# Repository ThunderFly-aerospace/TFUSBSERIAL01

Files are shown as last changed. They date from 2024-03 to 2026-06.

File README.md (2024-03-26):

# TFUSBSERIAL01 - USB-C to serial converter with Pixhawk telemetry JST-GH connector

The converter is designed to service operations on UAVs. It respects the [Pixhawk DS-009](https://github.com/pixhawk/Pixhawk-Standards/blob/master/DS-009%20Pixhawk%20Connector%20Standard.pdf) connector standard.

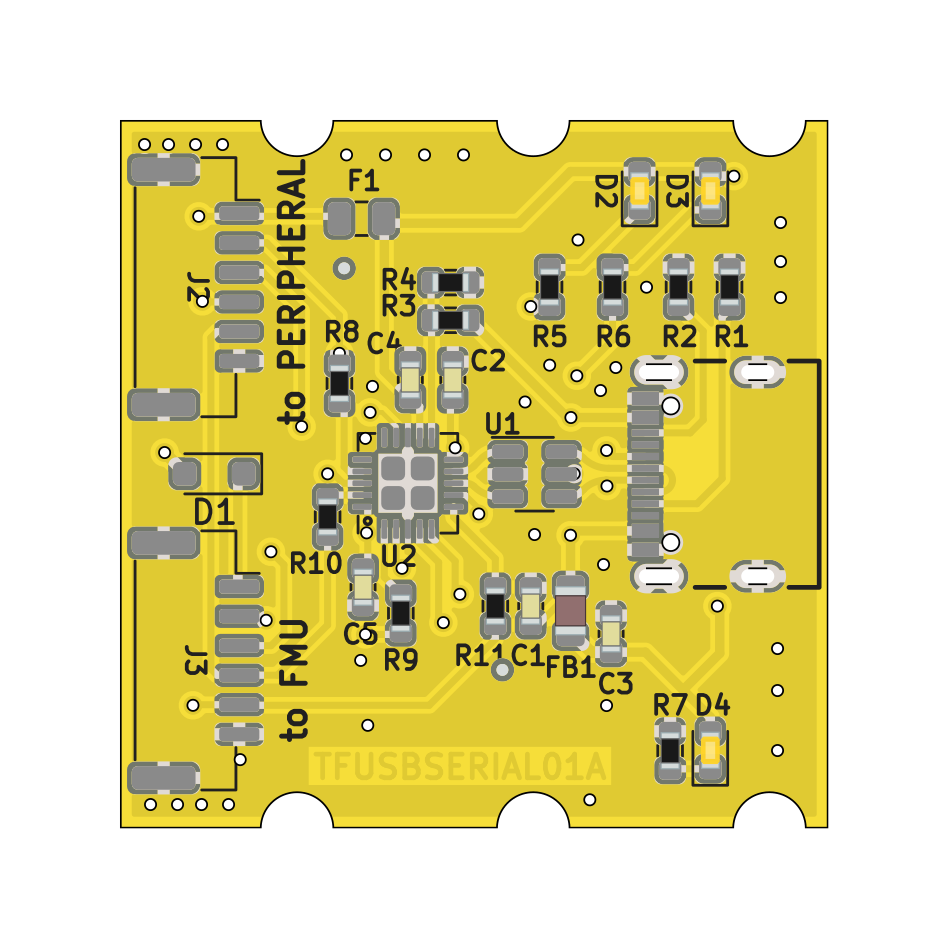
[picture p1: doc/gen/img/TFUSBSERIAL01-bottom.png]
TFUSBSERIAL01 Bottom


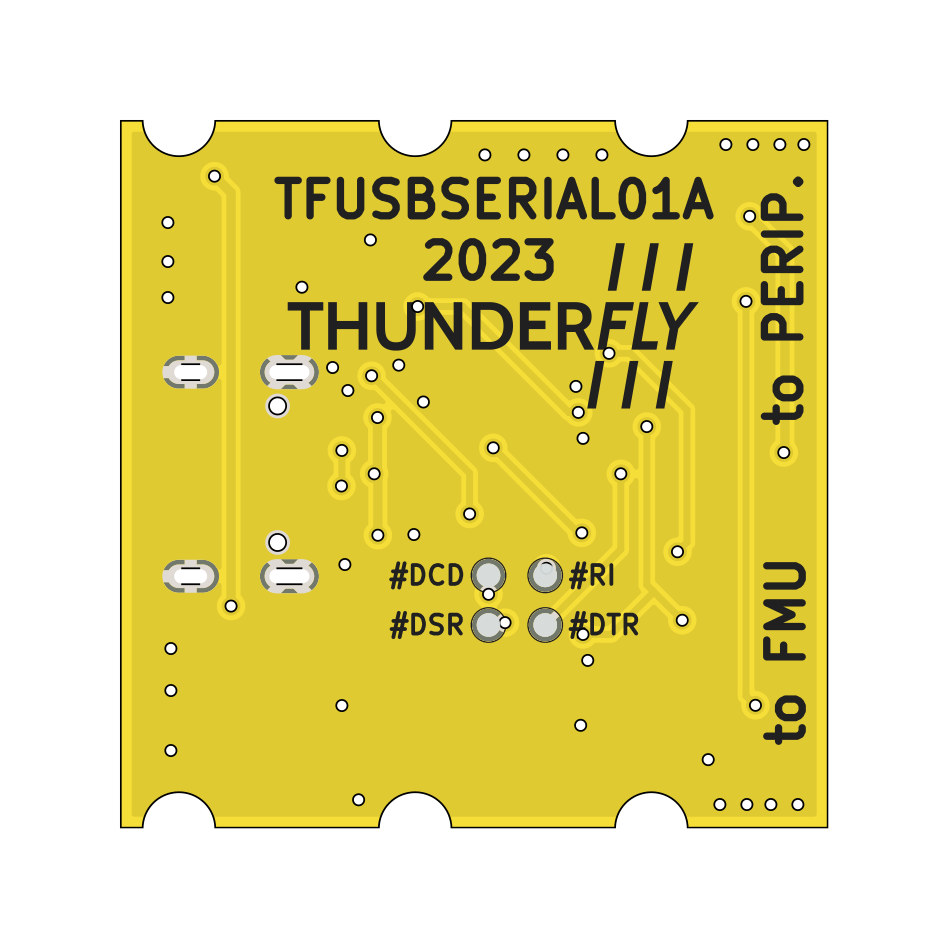
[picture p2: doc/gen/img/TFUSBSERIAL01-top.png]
TFUSBSERIAL01 Top


## Key features
 
  * Could be connected to both peripheral or FMUs
  * The FMU and peripheral connectors are separated, therefore there is no need for a special RX/TX cross-cable
  * Could be used for sniffing serial communication on telemetry links between autopilot and its peripheral (Both connectors could be used at once)
  * Supports hardware flow control
  * The power delivered from USB is protected from excess current possibly drawn by peripheral or FMU
  * The accidental power from FMU to USB is protected by reverse diode

### Where to Get It?
TFUSBSERIAL can be bought directly from ThunderFly via [email contact](https://www.thunderfly.cz/contact-us.html). The email can also be used if there are specific requirements for custom modifications and accessories (cables for example) or if the product will be inquired in significant quantities.

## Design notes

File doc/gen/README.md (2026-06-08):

# PCB

Board size: 30.0x30.0 mm (1.18x1.18 inches)

- This is the size of the rectangle that contains the board
- Thickness: 1.6 mm (63 mils)
- Material: FR4
- Finish: None
- Layers: 2
- Copper thickness: 35 µm

Solder mask: TOP / BOTTOM

- Color: Yellow

Silk screen: TOP / BOTTOM

- Color: Black

Stackup:

| Name | Type | Color | Thickness [µm]| Material | Er | Loss tan |
|---|---|---|---|---|---|---|
| F.SilkS | Top Silk Screen | Black | | | | |
| F.Mask | Top Solder Mask | Yellow | 10 | | | |
| F.Cu | copper | | 35 | | | |
| dielectric 1 | core | | 1510 | FR4 | 4.5 | 0.020 |
| B.Cu | copper | | 35 | | | |
| B.Mask | Bottom Solder Mask | Yellow | 10 | | | |
| B.Paste | Bottom Solder Paste  | | | | | |
| B.SilkS | Bottom Silk Screen | Black | | | | |

# Important sizes

Clearance: 0.2 mm (8 mils)

Track width: 0.2 mm (8 mils)

- By design rules: 0.2 mm (8 mils)

Drill: 0.5 mm (20 mils)

- Vias: 0.5 mm (20 mils) [Design: 0.4 mm (16 mils)]
- Pads: 0.65 mm (26 mils)
- The above values are real drill sizes, they add 0.1 mm (4 mils) to plated holes (PTH)

Via: 0.8/0.4 mm (31/16 mils)

- By design rules: 0.4/0.3 mm (16/12 mils)
- Micro via: yes [0.2/0.1 mm (8/4 mils)]
- Buried/blind via: yes
- Total: 59 (thru: 59 buried/blind: 0 micro: 0)

Outer Annular Ring: 0.15 mm (6 mils)

- By design rules: 0.05 mm (2 mils)

Eurocircuits class: 4B
- Using min drill 0.5 mm for an OAR of 0.15 mm

# General stats

Components count: (SMD/THT)

- Top: 0/6 (THT)
- Bottom: 29/0 (SMD)

Defined tracks:

- 0.2 mm (8 mils)
- 0.3 mm (12 mils)
- 0.4 mm (16 mils)
- 0.5 mm (20 mils)
- 0.6 mm (24 mils)
- 0.8 mm (31 mils)
- 0.86 mm (34 mils)

Used tracks:

- 0.2 mm (8 mils) (4) defined: yes
- 0.25 mm (10 mils) (3) defined: no
- 0.3 mm (12 mils) (128) defined: yes
- 0.4 mm (16 mils) (32) defined: yes
- 0.5 mm (20 mils) (6) defined: yes

Defined vias:

- 0.5/0.3 mm (20/12 mils)
- 0.8/0.4 mm (31/16 mils)

Used vias:

- 0.8/0.4 mm (31/16 mils) (Count: 59, Aspect: 2.0 A) defined: yes

Holes (excluding vias):

- 0.65 mm (26 mils) (2)
- 3.0 mm (118 mils) (6)

Oval holes:

- 0.6x1.4 mm (24x55 mils) (2)
- 0.6x1.7 mm (24x67 mils) (2)

Drill tools (including vias and computing adjusts and rounding):

- 0.5 mm (20 mils) (59)
- 0.65 mm (26 mils) (2)
- 0.7 mm (28 mils) (4)
- 3.0 mm (118 mils) (6)

Solder paste stats:

Using a paste with 87.75 % alloy, that has an specific gravity for the alloy of 7.4 g/cm³
and 1.0 g/cm³ for the flux. This paste has an specific gravity of  4.15 g/cm³.

The stencil thickness is  0.12 mm.

| Side | Pads with paste | Area [mm²] | Paste [g] |
|---|---|---|---|
| Total  | 102 | 75.81 | 0.38 |

Note: this is just an approximation to the theoretical value. Margins of the solder mask and waste aren't computed.

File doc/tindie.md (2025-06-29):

Simplify your UAV maintenance with the **TFUSBSERIAL01**, the essential tool for debugging and servicing UAV systems. This USB-C to serial converter is fully compliant with the [Pixhawk DS-009 connector standard](https://github.com/pixhawk/Pixhawk-Standards/blob/master/DS-009%20Pixhawk%20Connector%20Standard.pdf), ensuring seamless integration with your avionics equipment.

#### **Key Features:**
- **Dual Connection Flexibility:** Easily connect to both peripheral or FMUs without the need for special RX/TX crossover cables.
- **Simultaneous Communication:** Capable of sniffing serial communication on telemetry links, utilizing both connectors at once.
- **Advanced Safety Features:** Includes excess current protection for USB power and a reverse diode to prevent accidental power flow from FMU to USB.
- **Hardware Flow Control Support:** Ensures reliable data transfer, crucial for critical debugging tasks.

#### Easy Usage
Connect the FMU or peripheral device to the corresponding Pixhawk connector and utilize standard serial terminal tools for effective communication.

#### Effortless Self-Testing
Test cable functionality by connecting the "to FMU" and "to Peripheral" connectors, simulating a local echo for straightforward self-diagnostics.

# The package includes
- TFUSBSERIAL01A protected by the heat-shrinking tube
- 15cm UART/TELEM/SERIAL cable with JST-GH connectors. Color-coded by [ThunderFly color scheme](https://docs.thunderfly.cz/avionics/TFCAB01/).

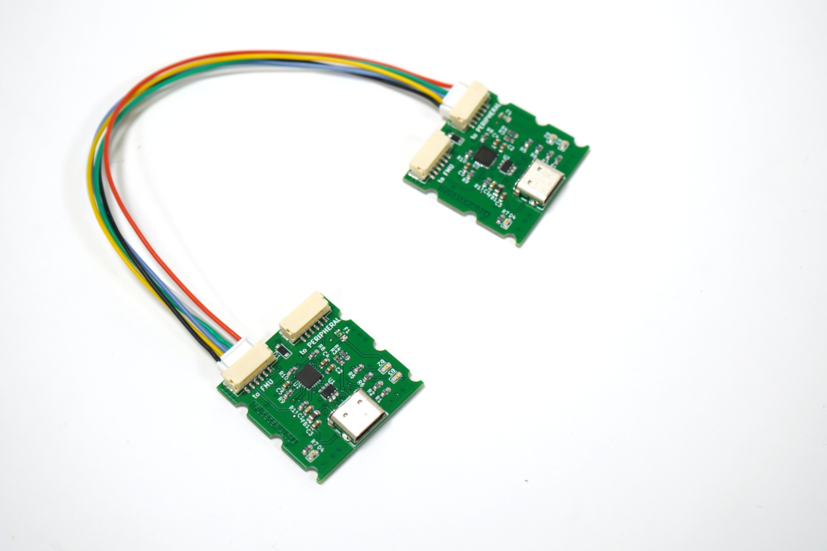
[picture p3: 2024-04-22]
doc/img/TFUSBSERIAL_MCU_PERIPHERAL.JPG

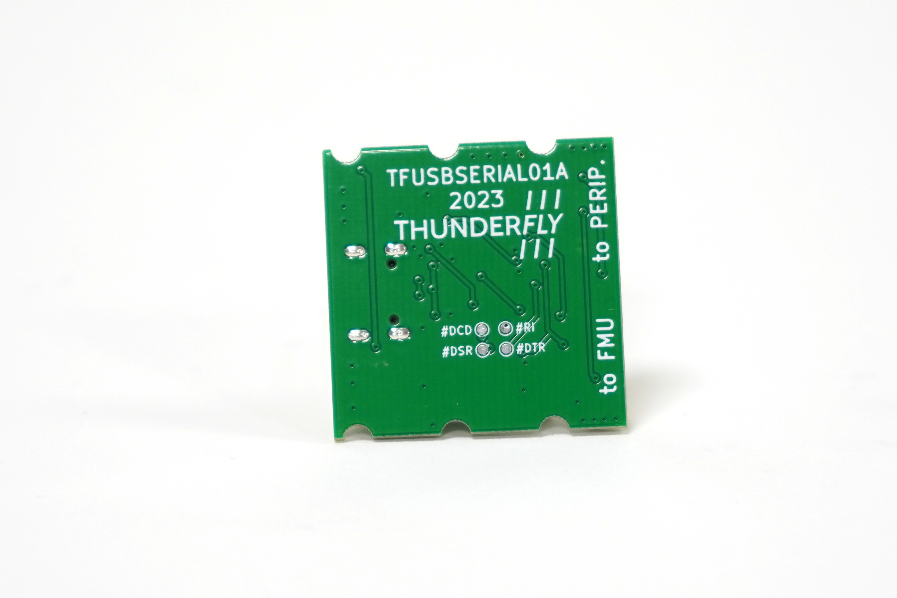
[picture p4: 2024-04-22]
doc/img/TFUSBSERIAL01_PCB.jpg

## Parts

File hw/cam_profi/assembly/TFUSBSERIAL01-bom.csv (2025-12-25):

Component | Description | Part | References | Value | Footprint | Quantity Per PCB | Datasheet | ust_id
1 | Unpolarized capacitor | C | C1 | 10nF | C_0603_1608Metric | 1 | ~ | 5c70984812875079b91f8bef
2 | Unpolarized capacitor | C | C2C4C5 | 100nF | C_0603_1608Metric | 3 | ~ | 5c70984812875079b91f8bf2
3 | Unpolarized capacitor | C | C3 | 10uF | C_0603_1608Metric | 1 | ~ | 5c70984812875079b91f8bf5
4 | Light emitting diode | LED | D3D4 | GREEN | LED_0603_1608Metric | 2 | ~ | 60d582331287500165f859d0
5 | Light emitting diode | LED | D2 | RED | LED_0603_1608Metric | 1 | ~ | 60d581db1287500165f859a2
6 | Diode | D | D1 | SRL23 | D_SOD-323_HandSoldering | 1 | https://www.tme.eu/Document/039d7772a3e1de850ecf12d397e62c7b/srl23.pdf | 651003fd462c6d9e72054b2f
7 | Resettable fuse, polymeric positive temperature coefficient | Polyfuse | F1 | 350mA | Fuse_0805_2012Metric | 1 | ~ | 650b8191462c6d9e7205477b
8 | Ferrite bead, small symbol | FerriteBead_Small | FB1 | BLM21PG300SN1D | L_0805_2012Metric | 1 | ~ | 5c70984412875079b91f87fd
9 | 1x07 2.54 mm pitch header | SM06B-GHS-TB | J2J3 | SM06B-GHS-TB | JST_GH_SM06B-GHS-TB_1x06-1MP_P1.25mm_Horizontal | 2 |  | 5fa0f70212875025b3977932
10 | USB 2.0-only Type-C Receptacle connector | USBC_USB4105-GF-A | J1 | USBC_USB4105-GF-A | USBC GCT_USB4105-GF-A | 1 |  | 5fa0f94612875025b397795e
11 | Resistor | R | R8R9R10R11 | 100R | R_0603_1608Metric | 4 | ~ | 5c70984512875079b91f8956
12 | Resistor | R | R6R7 | 130R | R_0603_1608Metric | 2 | ~ | 5cd08b17128750448e4542b1
13 | Resistor | R | R5 | 287R | R_0603_1608Metric | 1 | ~ | 651a975c462c6d9e7205504d
14 | Resistor | R | R3 | 4k7 | R_0603_1608Metric | 1 | ~ | 5c70984512875079b91f8960
15 | Resistor | R | R1R2 | 5k1 | R_0603_1608Metric | 2 | ~ | 628d1404dc56076e9a223650
16 | Resistor | R | R4 | 10k | R_0603_1608Metric | 1 | ~ | 5c70984512875079b91f8962
17 | Full Speed USB to Full Handshake UART, QFN-20 | FT231XQ | U2 | FT231XQ | QFN-20-1EP_4x4mm_P0.5mm_EP2.5x2.5mm | 1 | https://www.ftdichip.com/Support/Documents/DataSheets/ICs/DS_FT231X.pdf | 605d7fe0128750769e769adb
18 | Very low capacitance ESD protection diode, 2 data-line, SOT-23-6 | USBLC6-2SC6 | U1 | USBLC6-2SC6 | SOT-23-6 | 1 | https://www.st.com/resource/en/datasheet/usblc6-2.pdf | 5e82e0691287502a334a778c

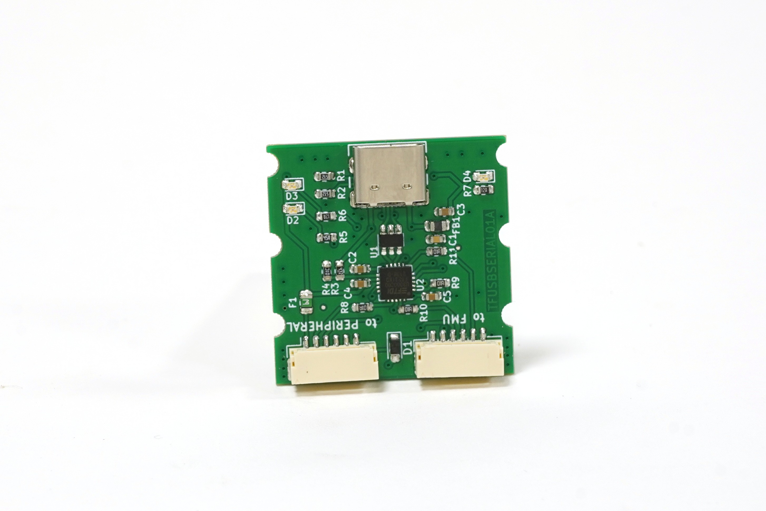
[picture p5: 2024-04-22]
doc/img/TFUSBSERIAL01_components.jpg

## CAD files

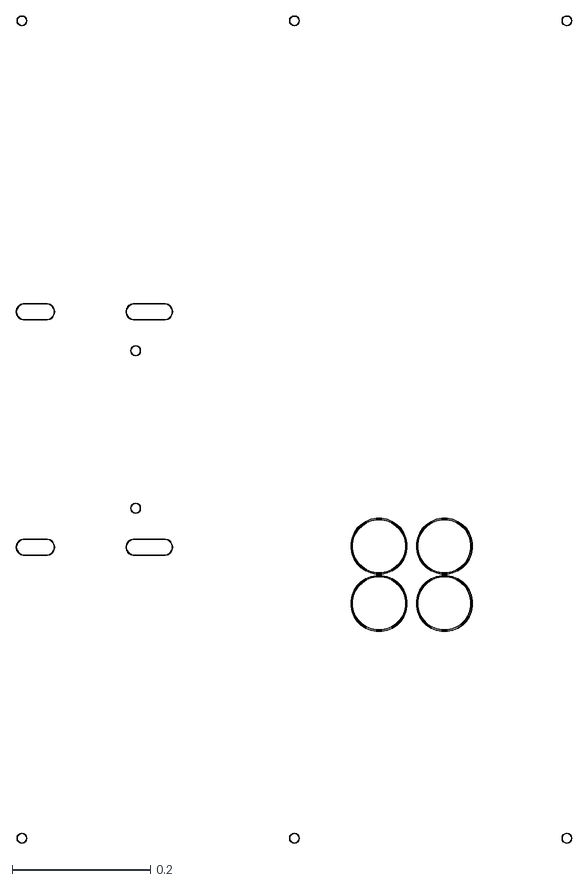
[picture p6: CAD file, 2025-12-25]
doc/gen/dxf/TFUSBSERIAL01-F_Courtyard.dxf
0.802 x 1.19

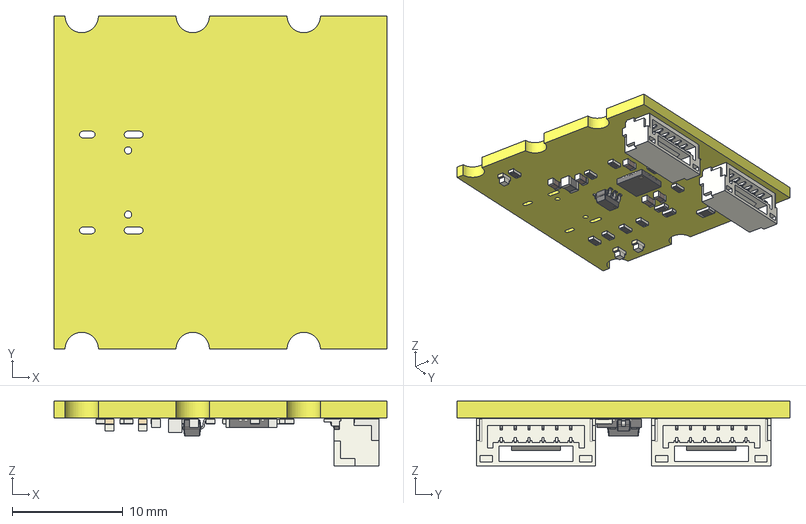
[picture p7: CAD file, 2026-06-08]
doc/gen/TFUSBSERIAL01.step
30.0 x 30.0 x 5.84 mm
D_SOD-323
LED_0603_1608Metric x 3
C_0603_1608Metric x 5
R_0603_1608Metric x 11
L_0805_2012Metric
JST_GH_SM06B-GHS-TB_1x06-1MP_P1.25mm_Horizontal x 2
QFN-20-1EP_4x4mm_P0.5mm_EP2.5x2.5mm
SOT-23-6
Fuse_0805_2012Metric
kibot_sx842oss_PCB

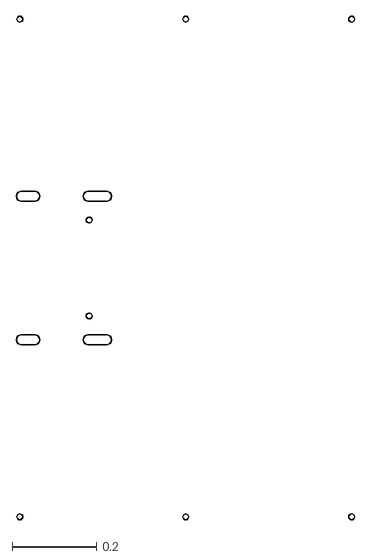
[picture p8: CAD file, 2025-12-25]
doc/gen/dxf/TFUSBSERIAL01-User_Drawings.dxf
0.802 x 1.19

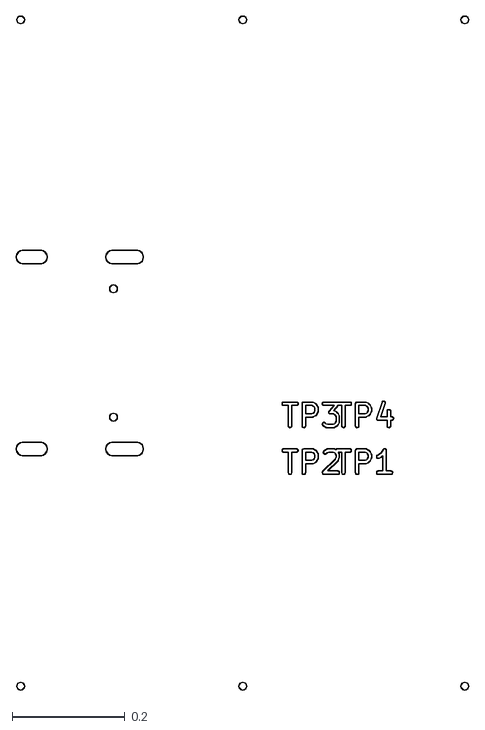
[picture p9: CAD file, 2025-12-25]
doc/gen/dxf/TFUSBSERIAL01-F_Fab.dxf
0.802 x 1.19

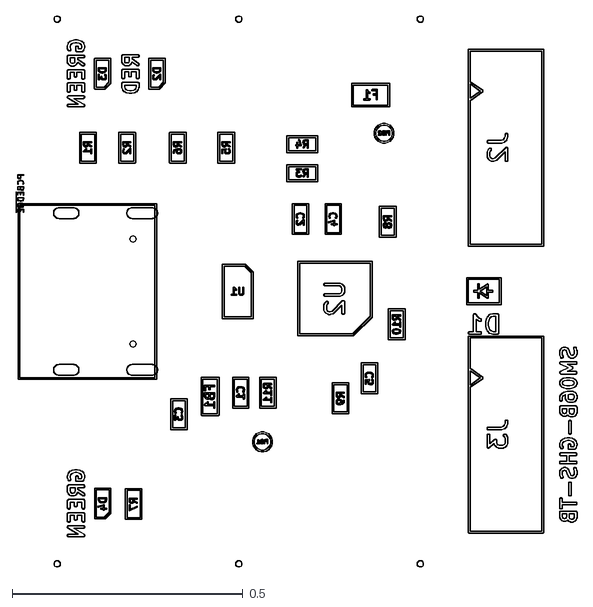
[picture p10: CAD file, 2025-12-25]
doc/gen/dxf/TFUSBSERIAL01-B_Fab.dxf
1.22 x 1.19

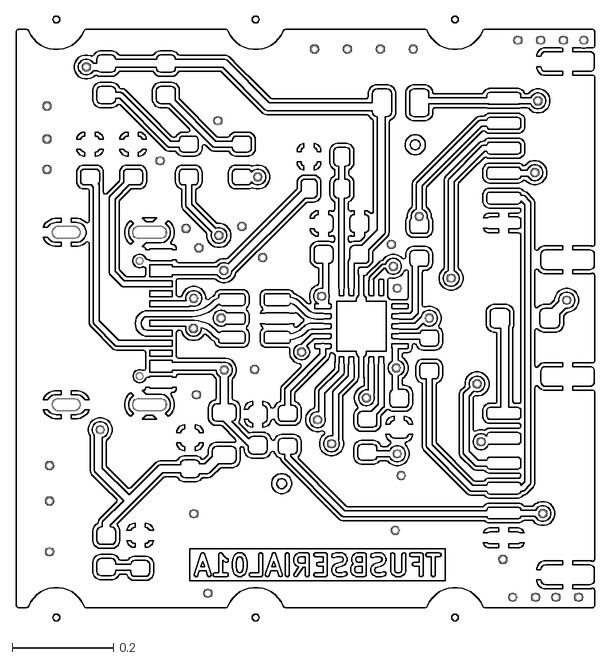
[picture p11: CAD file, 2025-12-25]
doc/gen/dxf/TFUSBSERIAL01-B_Cu.dxf
1.14 x 1.19

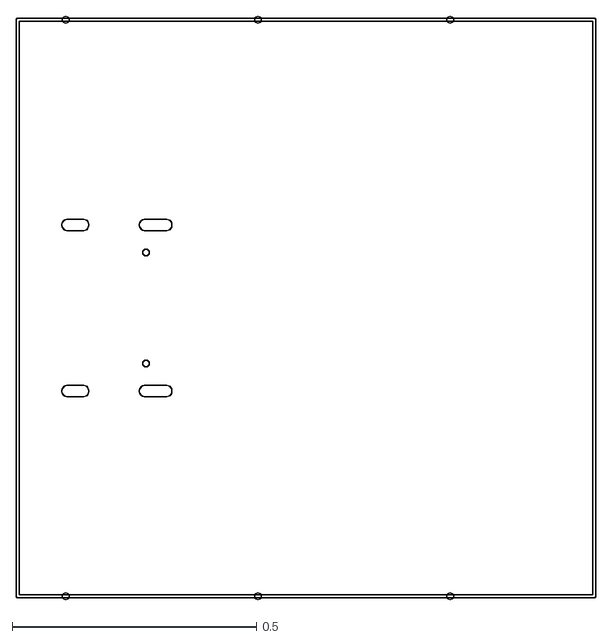
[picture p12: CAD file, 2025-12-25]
doc/gen/dxf/TFUSBSERIAL01-Edge_Cuts.dxf
1.19 x 1.19

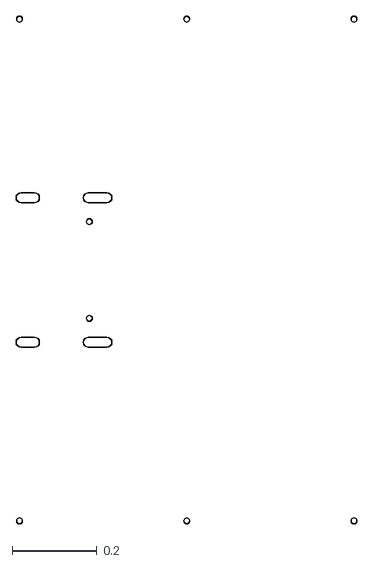
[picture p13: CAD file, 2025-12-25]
doc/gen/dxf/TFUSBSERIAL01-B_Adhesive.dxf
0.802 x 1.19

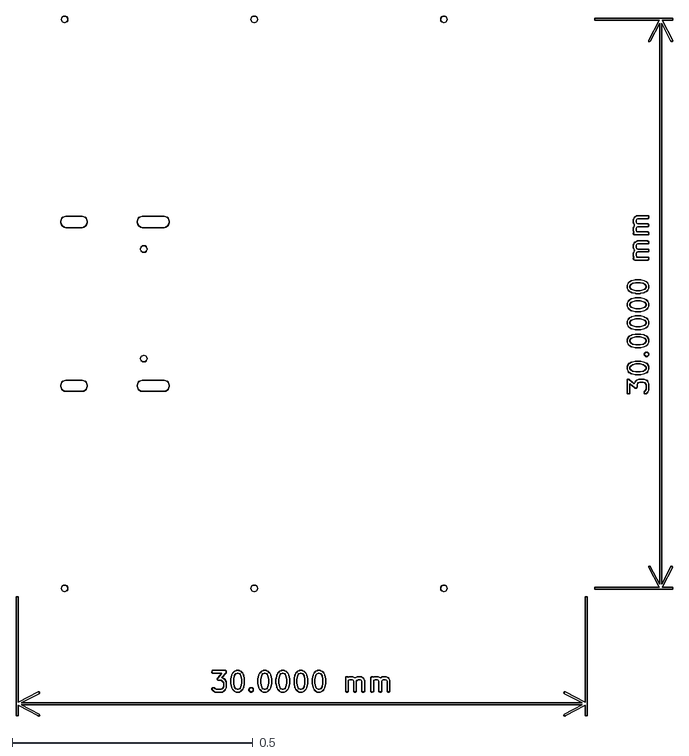
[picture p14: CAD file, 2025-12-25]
doc/gen/dxf/TFUSBSERIAL01-User_Comments.dxf
1.36 x 1.45

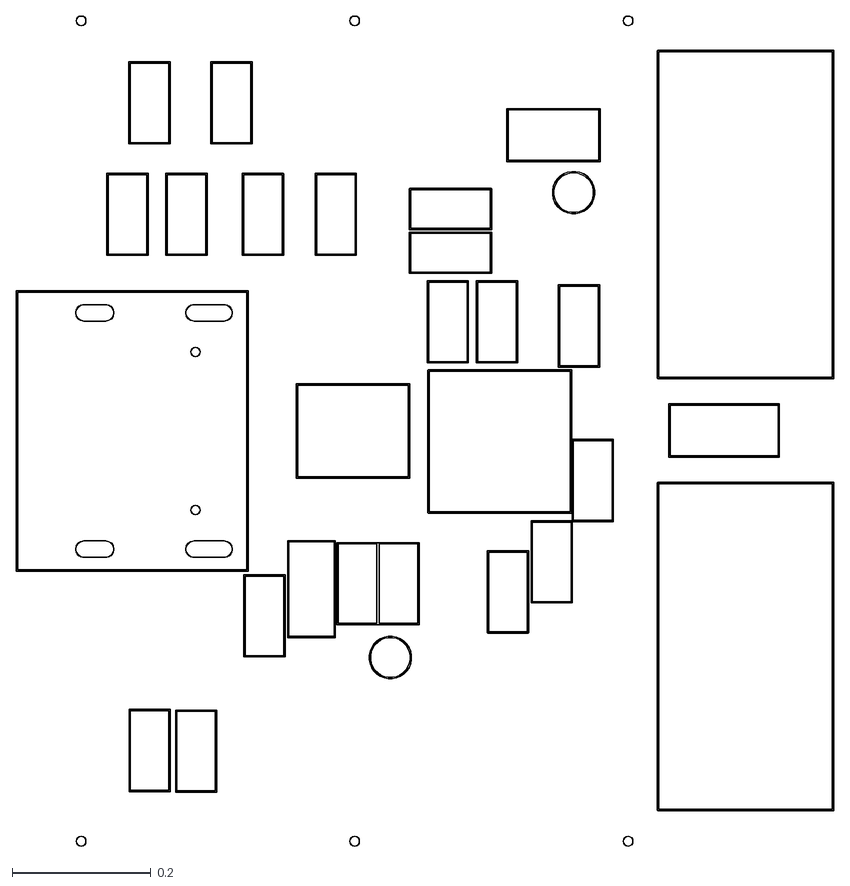
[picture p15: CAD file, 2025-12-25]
doc/gen/dxf/TFUSBSERIAL01-B_Courtyard.dxf
1.18 x 1.19

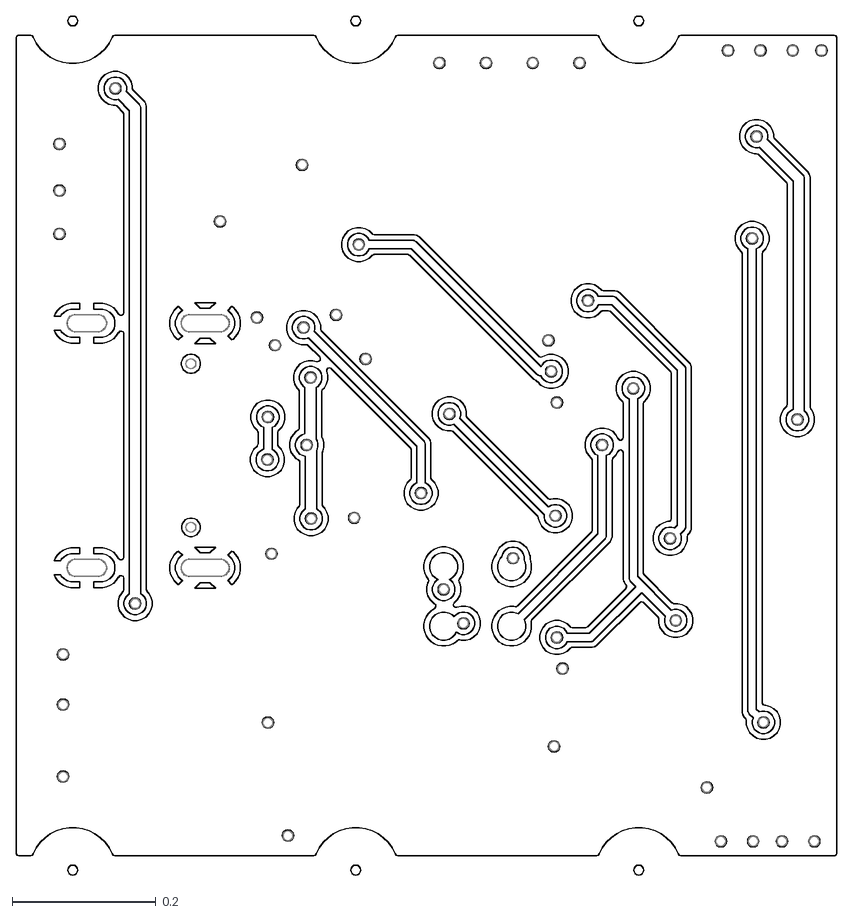
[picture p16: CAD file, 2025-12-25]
doc/gen/dxf/TFUSBSERIAL01-F_Cu.dxf
1.14 x 1.19

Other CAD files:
doc/gen/dxf/TFUSBSERIAL01-B_Mask.dxf
doc/gen/dxf/TFUSBSERIAL01-B_Paste.dxf
doc/gen/dxf/TFUSBSERIAL01-B_Silkscreen.dxf
doc/gen/dxf/TFUSBSERIAL01-F_Mask.dxf
doc/gen/dxf/TFUSBSERIAL01-F_Silkscreen.dxf

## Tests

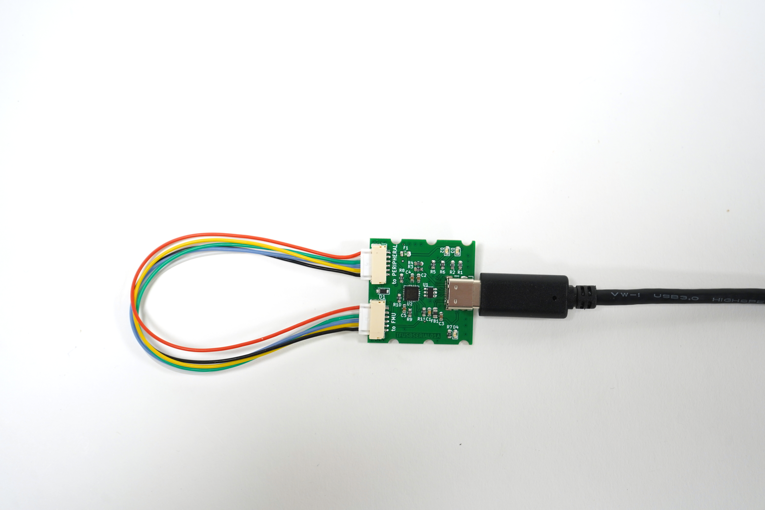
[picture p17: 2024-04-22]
doc/img/TFUSBSERIAL01_self-test.jpg

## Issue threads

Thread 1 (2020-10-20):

Výstupní JST-GH konektor

kaklik, 2020-10-20:
zapojení konektoru by mělo umožnit přímé připojení k autopilotímu TELEMETRY konektoru.

Pro připojení na TFMODEM zřejmě bude potřeba prokřížený JST-GH propojovací kabel.

roman-dvorak, 2021-05-14:
Připadalo by mi užitečnější mít konektor tak, aby šlo použít přímý kabel pro propojení se zařízeními. Které se obvykle takto konfigurují.

Pak by byla varianta mít na modulu 2 konektory. Jeden z pohledu autopilota a druhý z pohledu zařízení. Aby křížený kabel nemusel existovat.

kaklik, 2021-05-14:
> Pak by byla varianta mít na modulu 2 konektory. Jeden z pohledu autopilota a druhý z pohledu zařízení. Aby křížený kabel nemusel existovat.

Souhlasím, dva konektory mi přijdou jako nejlepší řešení tohoto problému.

kaklik, 2023-08-03:
Navrhoval bych tomu konektoru pro device říkat Peripheral connector stejně jako to dělá Pixhawk.

kaklik, 2023-09-30:
Tohle je už vyřešené.

Closed 2023-09-30.

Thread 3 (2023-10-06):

TX and RX LED marking missing in Silkscreen

kaklik, 2023-10-06:
Na desce není označeno u LED, která odpovídá RX a která TX.

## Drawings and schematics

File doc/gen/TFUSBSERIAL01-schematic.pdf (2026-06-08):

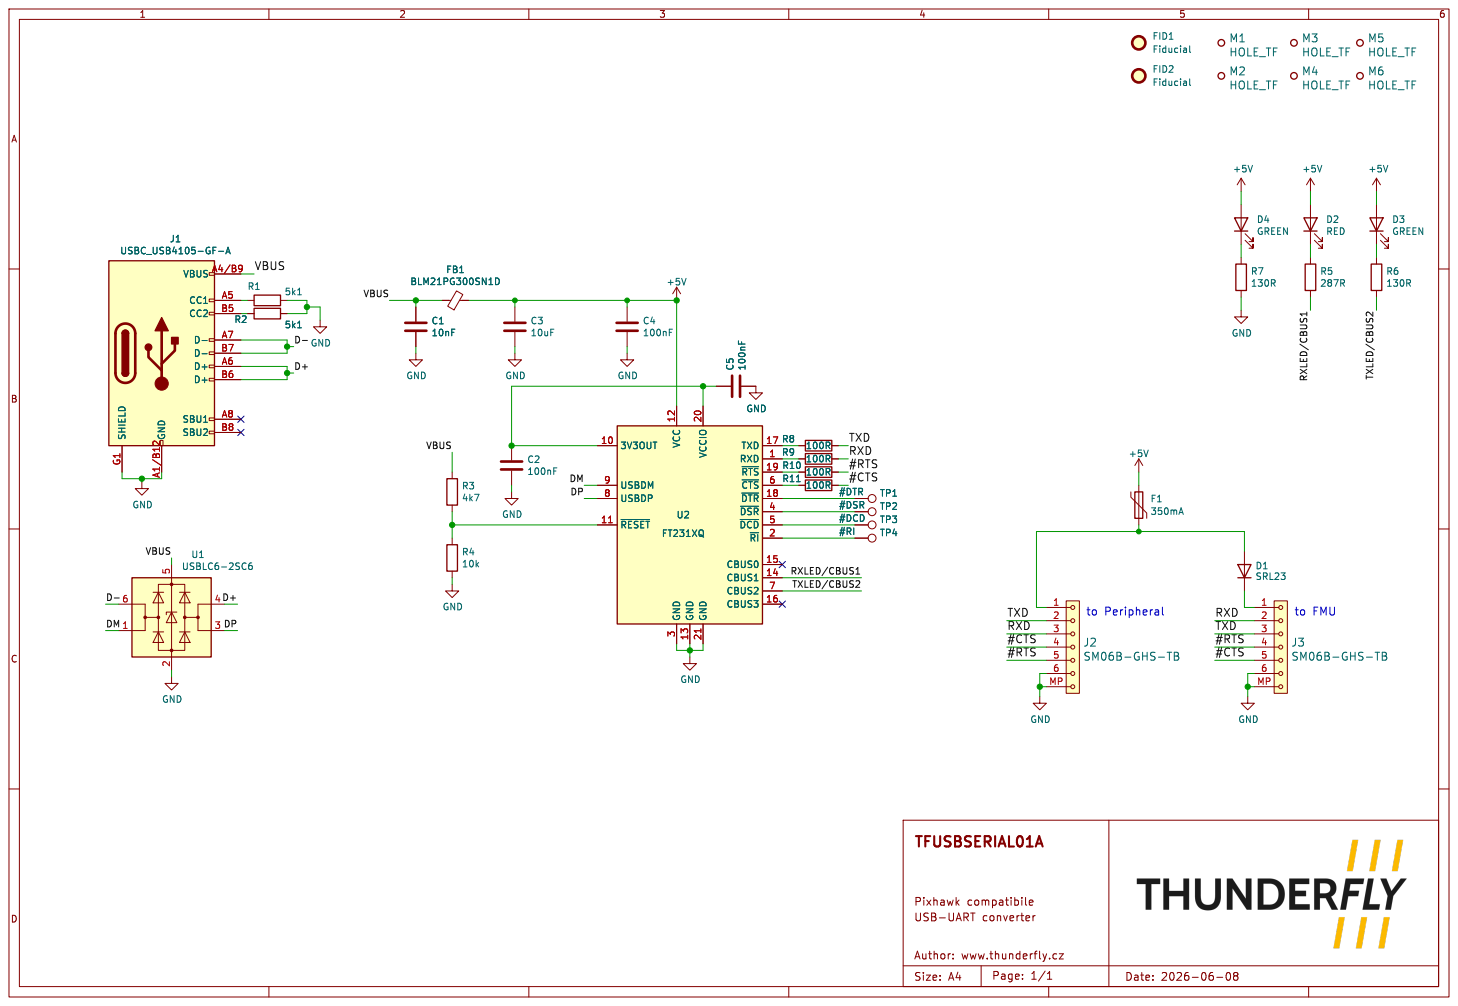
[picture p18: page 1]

3 GND 13 VCCIO 20 GND 21 TXD 17 RXD 1 ~{RTS}19 ~{CTS}6 ~{DTR}18 ~{DSR}4 ~{DCD}5 ~{RI}2 CBUS0 15 CBUS1 14 CBUS2 7 CBUS3 16 U2 FT231XQ

3 GND 13 VCCIO 20 GND 21 TXD 17 RXD 1 ~{RTS}19 ~{CTS}6 ~{DTR}18 ~{DSR}4 ~{DCD}5 ~{RI}2 CBUS0 15 CBUS1 14 CBUS2 7 CBUS3 16 R8 100R R9 100R R10 100R R11 100R

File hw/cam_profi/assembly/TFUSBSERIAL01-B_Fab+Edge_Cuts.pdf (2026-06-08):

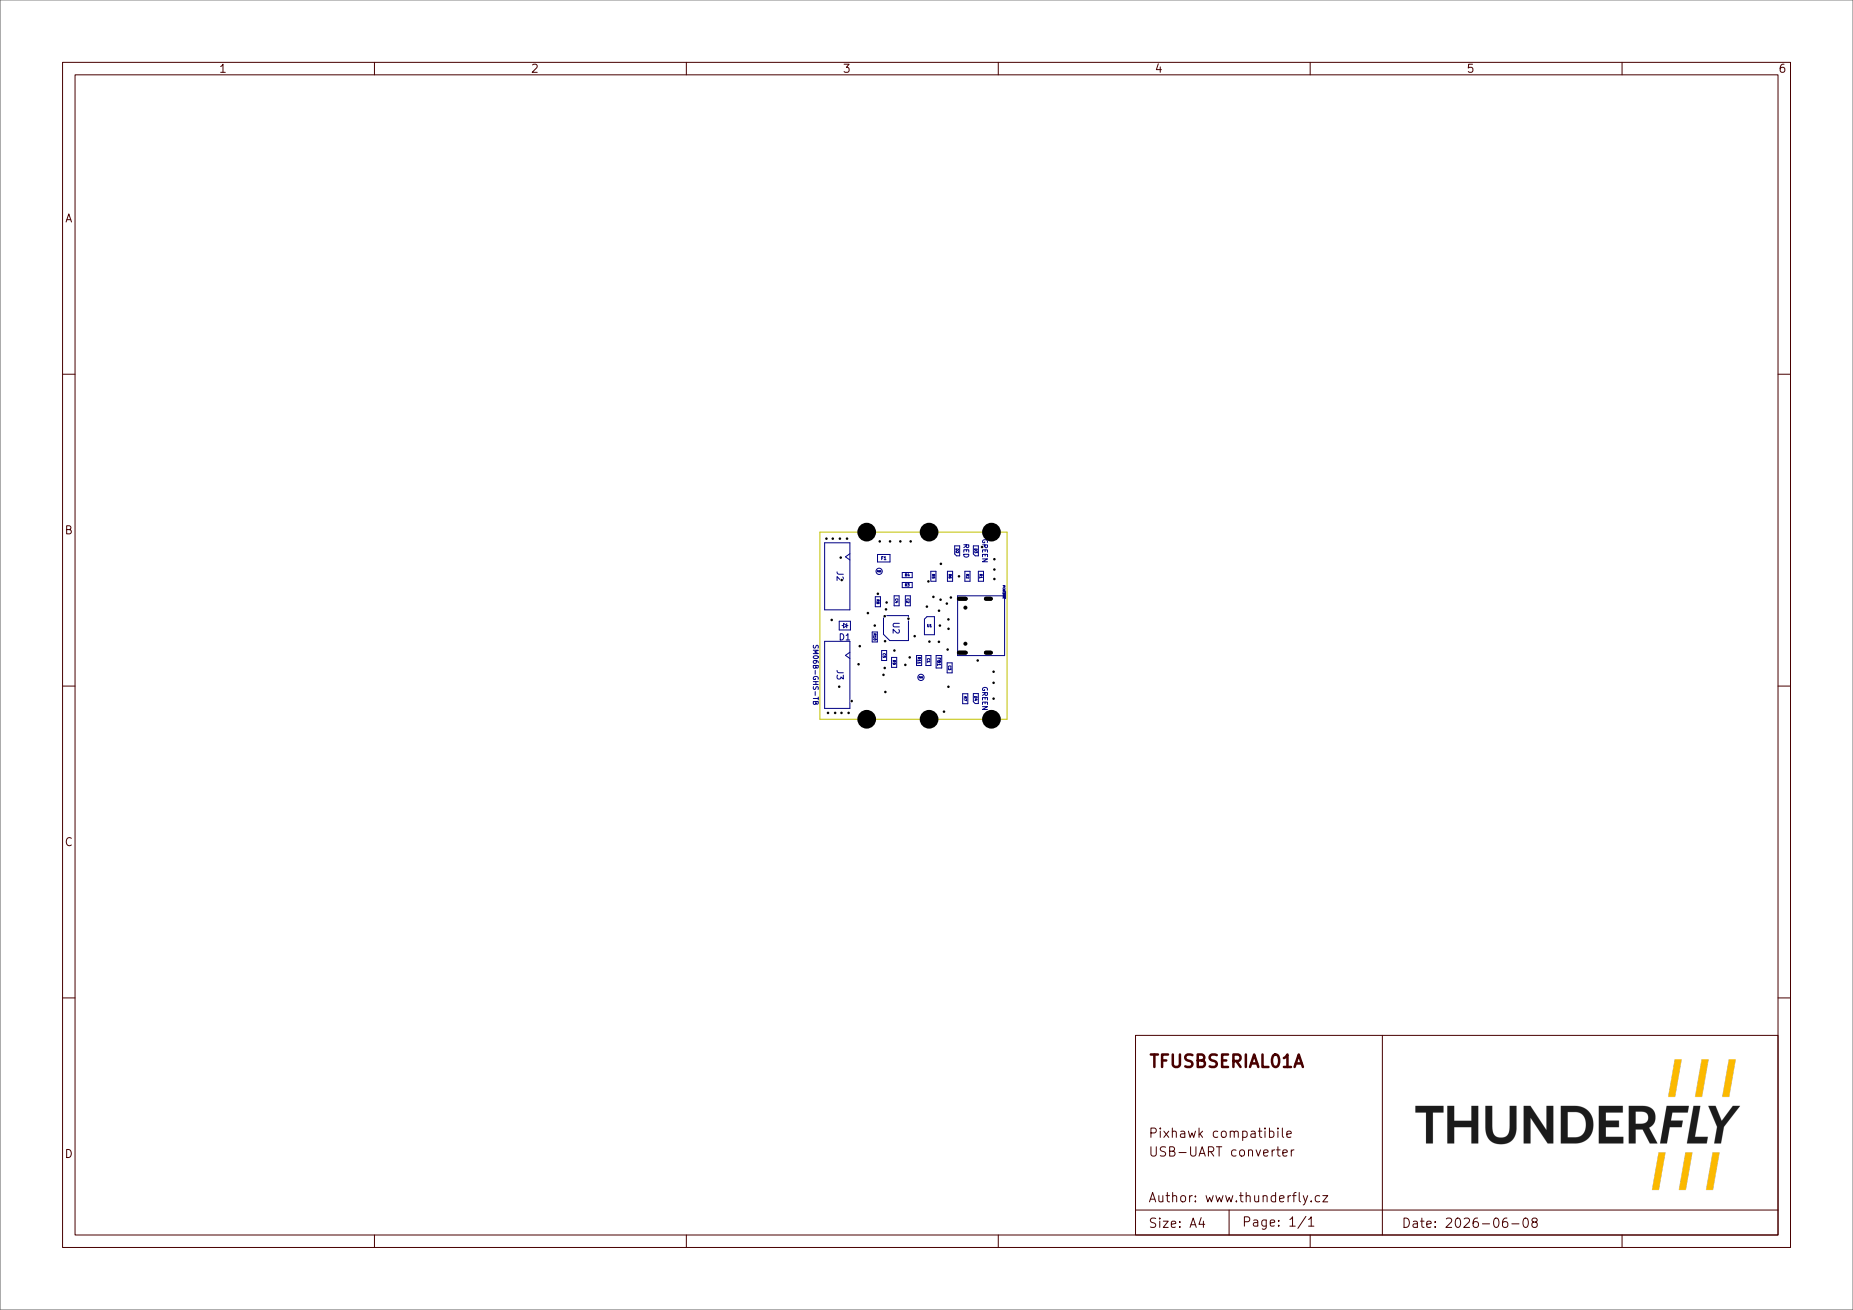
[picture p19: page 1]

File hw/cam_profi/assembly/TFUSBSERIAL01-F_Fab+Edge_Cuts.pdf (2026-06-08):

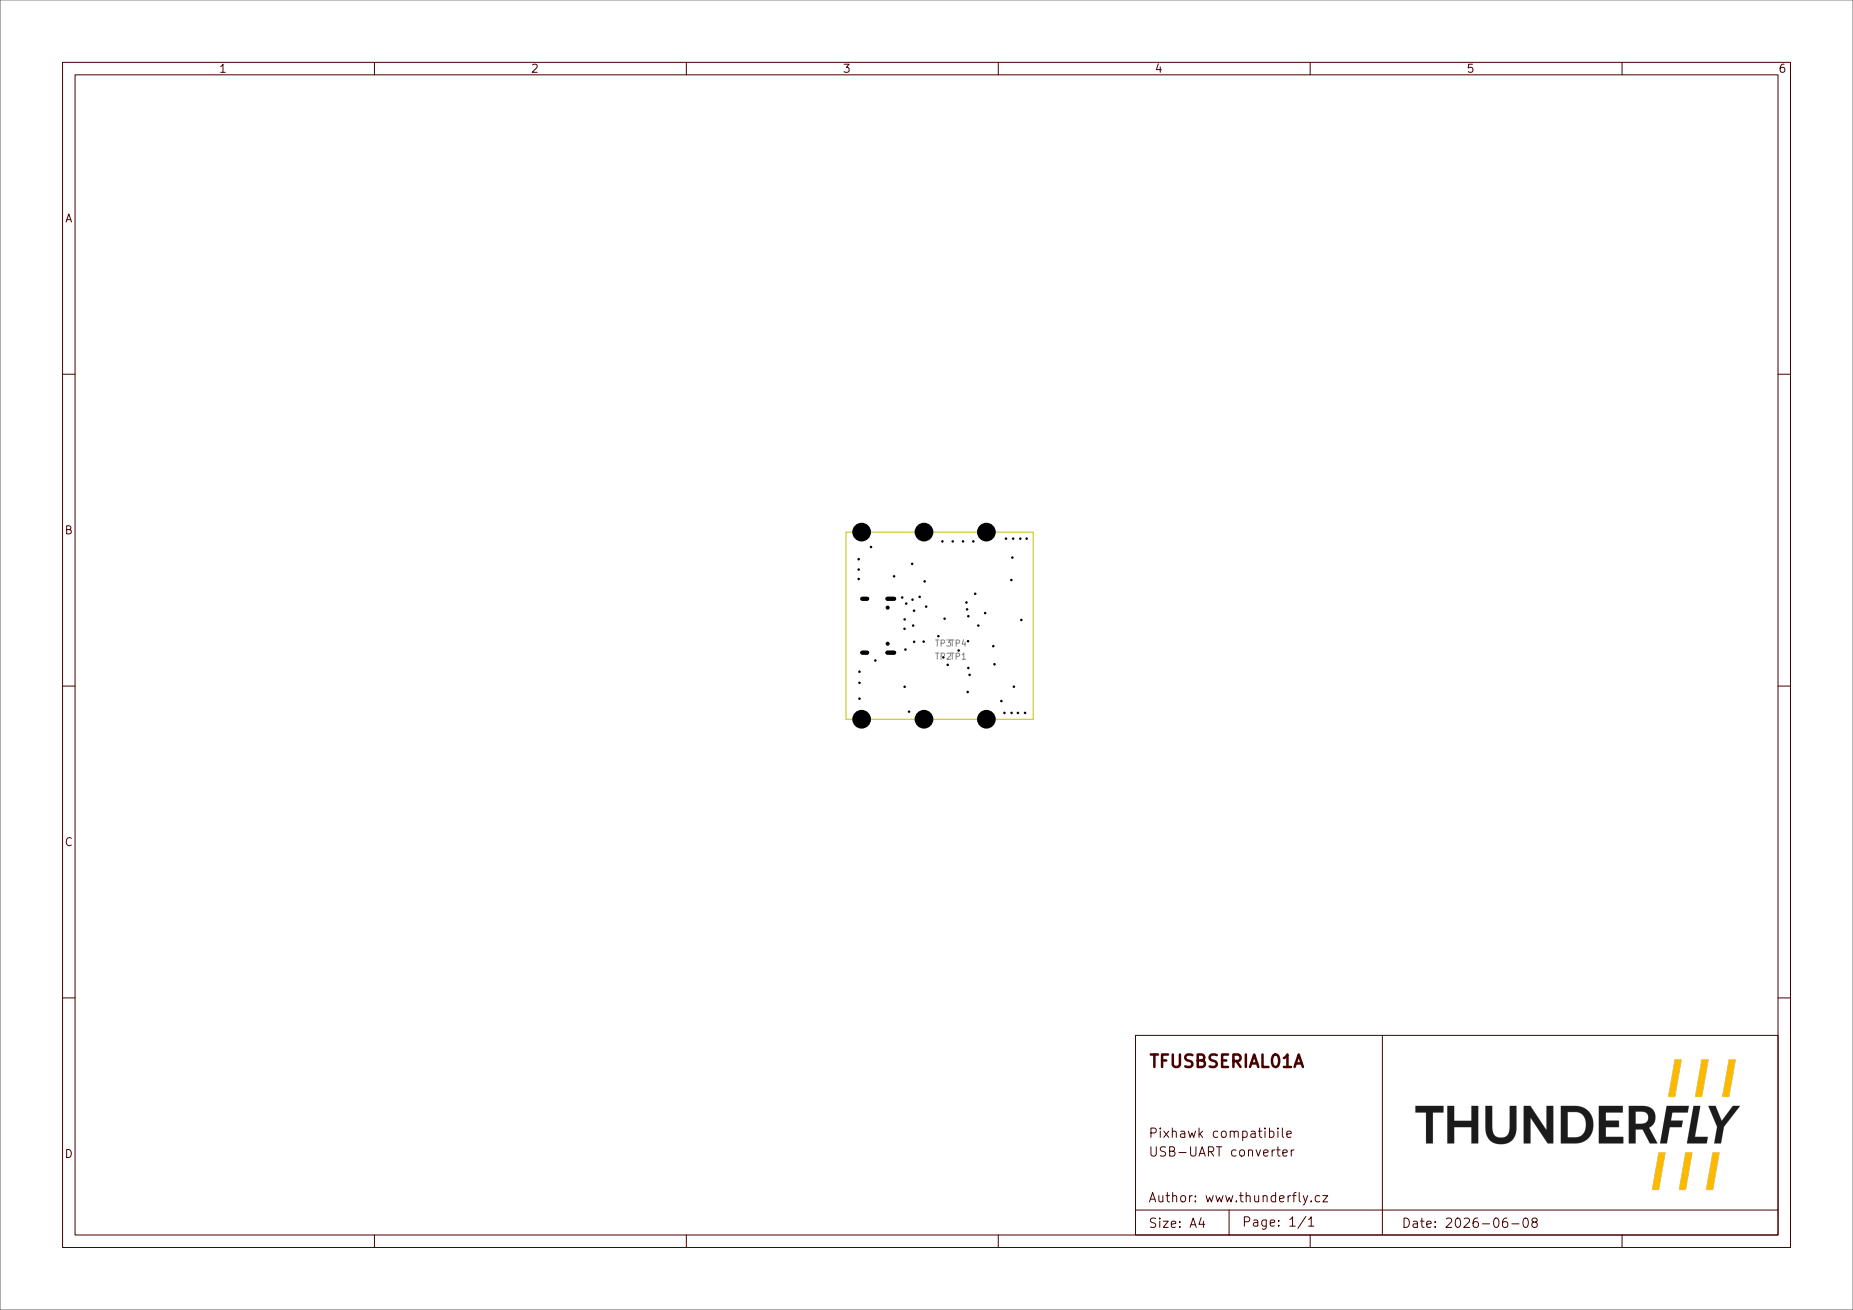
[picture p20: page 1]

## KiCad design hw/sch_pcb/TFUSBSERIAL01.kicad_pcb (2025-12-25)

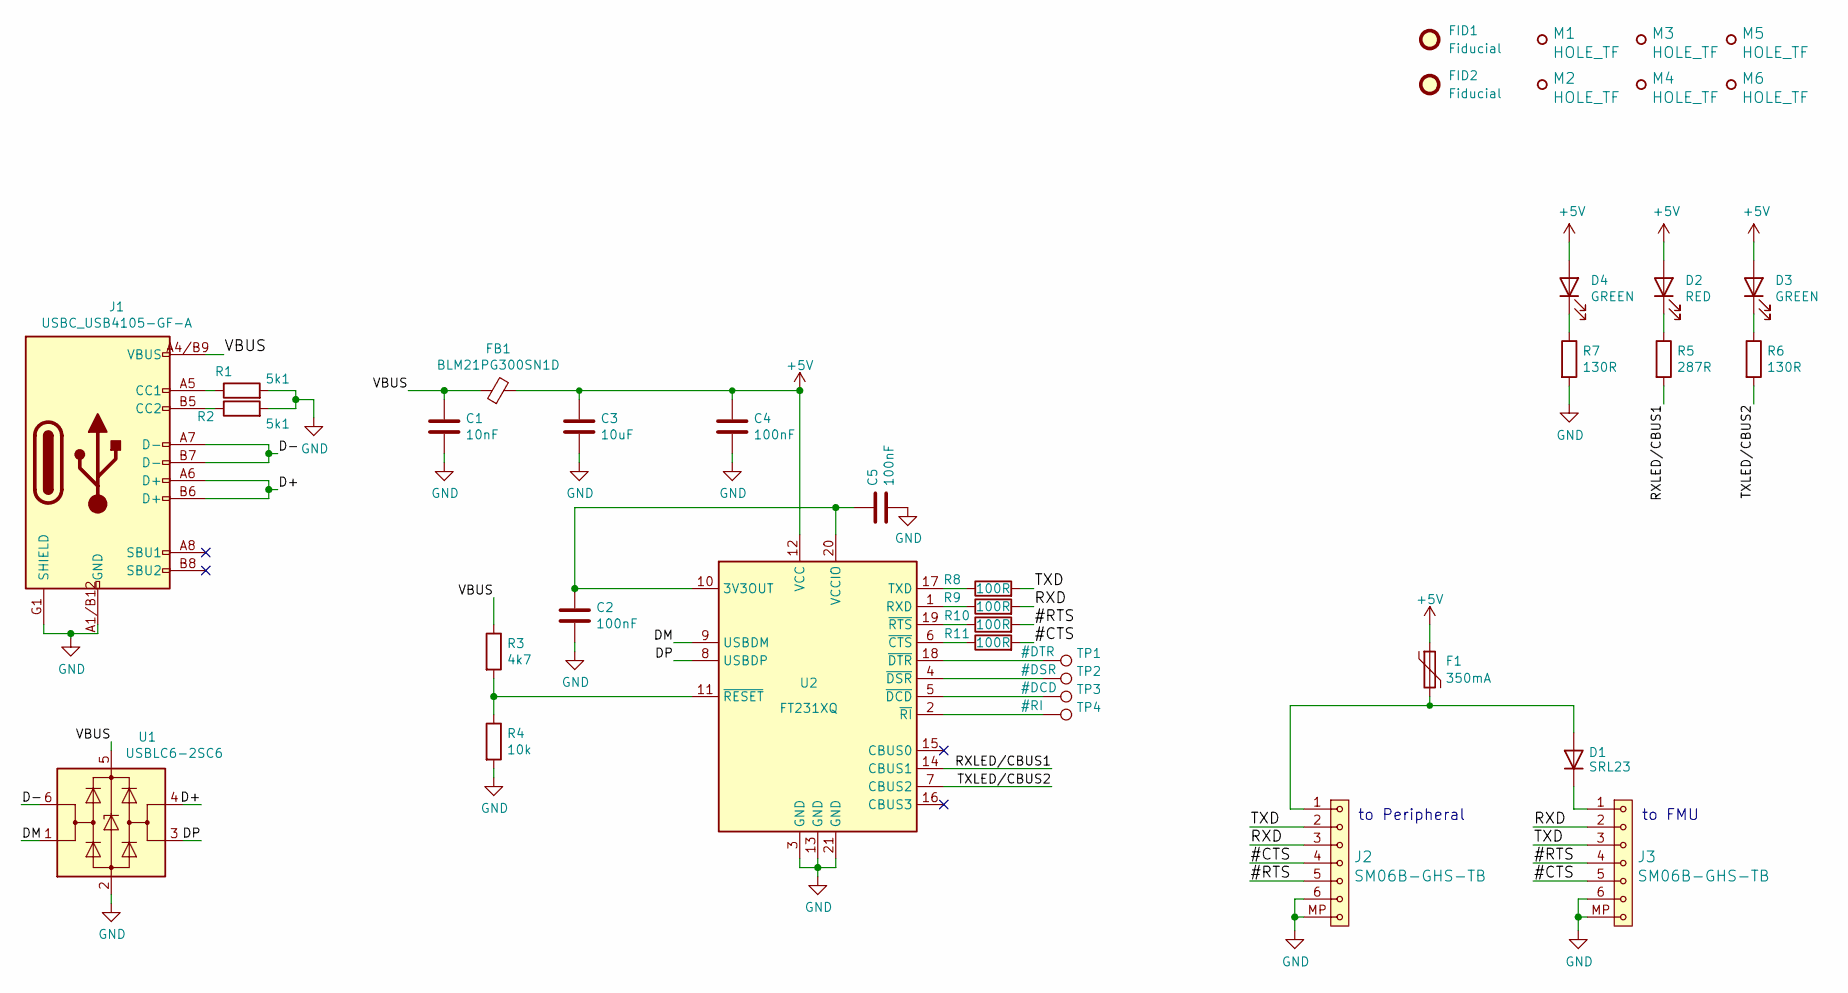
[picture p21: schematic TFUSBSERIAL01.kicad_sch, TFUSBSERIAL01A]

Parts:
C1: 10nF; C_0603_1608Metric
C2, C4, C5: 100nF; C_0603_1608Metric
C3: 10uF; C_0603_1608Metric
D1: SRL23; D_SOD-323_HandSoldering
D2: RED; LED_0603_1608Metric
D3, D4: GREEN; LED_0603_1608Metric
F1: 350mA; Fuse_0805_2012Metric
FB1: BLM21PG300SN1D; L_0805_2012Metric
FID1, FID2: Fiducial; Fiducial_0.5mm_Mask1mm
J1: USBC_USB4105-GF-A; USBC GCT_USB4105-GF-A
J2, J3: SM06B-GHS-TB; JST_GH_SM06B-GHS-TB_1x06-1MP_P1.25mm_Horizontal
M1, M2, M3, M4, M5, M6: HOLE_TF; dira_3mm
R1, R2: 5k1; R_0603_1608Metric
R3: 4k7; R_0603_1608Metric
R4: 10k; R_0603_1608Metric
R5: 287R; R_0603_1608Metric
R6, R7: 130R; R_0603_1608Metric
R8, R9, R10, R11: 100R; R_0603_1608Metric
TP1: #DTR; TestPoint_Pad_D1.0mm
TP2: #DSR; TestPoint_Pad_D1.0mm
TP3: #DCD; TestPoint_Pad_D1.0mm
TP4: #RI; TestPoint_Pad_D1.0mm
U1: USBLC6-2SC6; SOT-23-6
U2: FT231XQ; QFN-20-1EP_4x4mm_P0.5mm_EP2.5x2.5mm

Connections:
+5V: C3.1, C4.1, D2.2 (A), D3.2 (A), D4.2 (A), F1.1, FB1.2, U2.12 (VCC)
/#CTS: J2.4, J3.5, R11.2
/#RTS: J2.5, J3.4, R10.2
/D+: J1.A6 (D+), J1.B6 (D+), U1.4 (I/O2)
/D-: J1.A7 (D-), J1.B7 (D-), U1.6 (I/O1)
/DM: U1.1 (I/O1), U2.9 (USBDM)
/DP: U1.3 (I/O2), U2.8 (USBDP)
/RXD: J2.3, J3.2, R9.2
/RXLED/CBUS1: R5.2, U2.14 (CBUS1)
/TXD: J2.2, J3.3, R8.2
/TXLED/CBUS2: R6.2, U2.7 (CBUS2)
/VBUS: C1.1, FB1.1, J1.A4/B9 (VBUS), J1.B4/A9 (VBUS), R3.1, U1.5 (VBUS)
GND: C1.2, C2.2, C3.2, C4.2, C5.2, J1.A1/B12 (GND), J1.B1/A12 (GND), J1.G1 (SHIELD), J1.G2 (SHIELD), J1.G3 (SHIELD), J1.G4 (SHIELD), J2.6, J2.MP, J3.6, J3.MP, R1.2, R2.2, R4.2, R7.2, U1.2 (GND), U2.3 (GND), U2.13 (GND), U2.21 (GND)
unnamed: D1.2 (A), F1.2, J2.1
unnamed: D1.1 (K), J3.1
unnamed: D2.1 (K), R5.1
unnamed: D3.1 (K), R6.1
unnamed: D4.1 (K), R7.1
unnamed: J1.A5 (CC1), R1.1
unnamed: J1.B5 (CC2), R2.1
unnamed: C2.1, C5.1, U2.10 (3V3OUT), U2.20 (VCCIO)
unnamed: R9.1, U2.1 (RXD)
unnamed: R8.1, U2.17 (TXD)
unnamed: R11.1, U2.6 (~CTS)
unnamed: TP3.1, U2.5 (~DCD)
unnamed: TP2.1, U2.4 (~DSR)
unnamed: TP1.1, U2.18 (~DTR)
unnamed: R3.2, R4.1, U2.11 (~RESET)
unnamed: TP4.1, U2.2 (~RI)
unnamed: R10.1, U2.19 (~RTS)

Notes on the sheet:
to Peripheral
to FMU

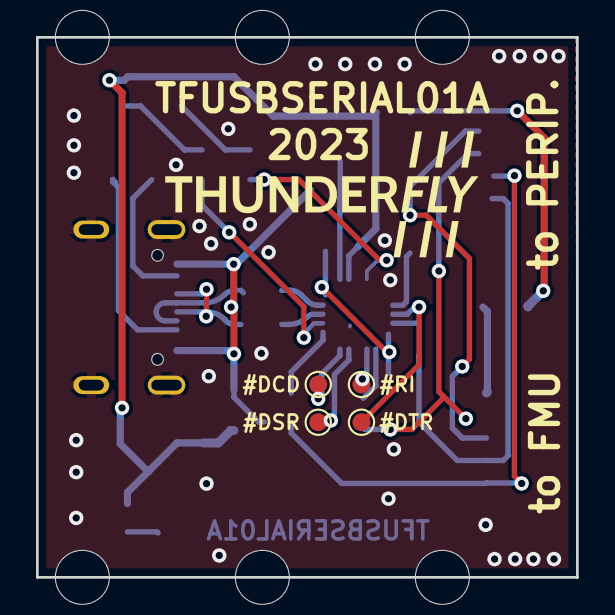
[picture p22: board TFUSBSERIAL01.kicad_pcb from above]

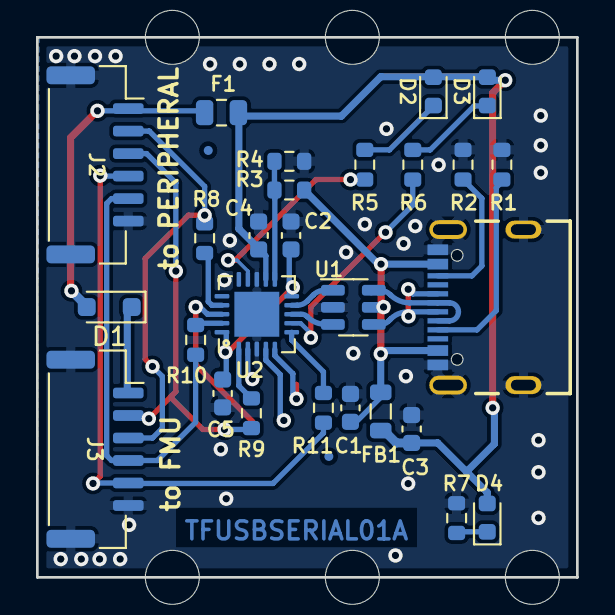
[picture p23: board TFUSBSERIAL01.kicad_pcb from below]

Board: 2 copper layers, 30.0 x 30.0 mm, 39 parts (29 on the bottom side), 30 nets.

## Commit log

2021-05-21 Edit PCB
    [TFUSBSERIAL01A.kicad_pcb, TFUSBSERIAL01A.kicad_sch]
2021-05-27 Edit SCH and PCB
    [TFUSBSERIAL01A.kicad_pcb, TFUSBSERIAL01A.kicad_sch]
2023-08-03 Procisteni repozitare
    [TFUSBSERIAL01.kicad_pcb, TFUSBSERIAL01.kicad_sch, TFUSBSERIAL01A.kicad_pcb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]
2023-08-03 Update actions products
    [TFUSBSERIAL01-B_Courtyard.dxf, TFUSBSERIAL01-B_Cu.dxf, TFUSBSERIAL01-B_Fab.dxf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]
2023-08-03 Edit schema
    [TFUSBSERIAL01.kicad_sch]
2023-08-03 Change fuse schematics symbol to polyfuse Solve some offgrid placed componets Rename Device connector to peripheral connector.
    [TFUSBSERIAL01.kicad_sch]
2023-09-20 usb serial
    [TFUSBSERIAL01.kicad_pcb, TFUSBSERIAL01.kicad_sch]
2023-09-20 update silkscreen
    [TFUSBSERIAL01.kicad_pcb]
2023-09-20 update ust_id
    [TFUSBSERIAL01.kicad_sch]
2023-09-22 layout updates
    [TFUSBSERIAL01.kicad_pcb, TFUSBSERIAL01.kicad_sch]
2023-09-24 Kontrola a upravy pred vyrobou.
    [TFUSBSERIAL01.kicad_pcb, TFUSBSERIAL01.kicad_sch]
2023-09-29 exclude mechanical components from BOM.
    [TFUSBSERIAL01.kicad_sch]
2023-10-02 Edit UST_ID
    [TFUSBSERIAL01.kicad_sch]
2023-10-04 Edit B.Fab
    [TFUSBSERIAL01.kicad_pcb]
2024-04-23 Add PCB dimensions.
    [TFUSBSERIAL01.kicad_pcb]
2025-12-25 Update title block. Update project to KiCADv9.
    [TFUSBSERIAL01.kicad_pcb, TFUSBSERIAL01.kicad_sch]
2026-06-08 Add NextIntranet ibom user.js injection and update submodule
    - Update doc/assets submodule to KiCADv9 cab59cd (ibom_user.js + defaults)
    - kicad_outputs.yml: inject ibom_user.js into generated ibom HTML after KiBot
